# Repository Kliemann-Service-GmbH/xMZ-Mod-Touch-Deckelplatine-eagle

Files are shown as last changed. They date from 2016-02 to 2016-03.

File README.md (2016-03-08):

# xMZ-Mod-Touch
## Eagle Dateien Bodenplatine

## Howto's
### Material Listen (BOM) erstellen

Die Material Listen werden aus den Eagle Zeichnungen gewonnen. Hierzu werden in
Eagle zunächst über den "design link" alle Bauteile in der Farnell Datenbank
gesucht. Anschließend wird diese Liste gespeicherti (Design Link Export).

* Dateiname: "Deckelplatine $VERSION-order.txt"

Danach wird das bom.ulp in Eagle ausgeführt. Folgende Einstellungen sind zu
wählen:

	Listen-Typ: Werte (Häckchen unter "Attribute auflisten" setzen)
	Ausgabeformat: CSV

Diese Datei wird ebenfalls gespeichert.

* Dateiname: "Deckelplatine $VERSION BOM.csv"

### Farnell BOM Import

Farnell bietet die Möglichkeit über eine Web GUI die BOM Daten in eine
Bestellung umzuwandeln.

Format der CSV Datei für den Import:
- 3 Spalten ("Anzahl;	Ordercode; Beschreibung")
- Dateiformat .xlsx oder .xls

#Produktionsdaten
## Dokumentation Boardlayout Dateien

Einige der wichtigsten Ebenen (Drill, Solder, Paste) wurden einzeln zusammen
mit der "Document" Ebene (Layer 48) als PDF gedruckt (Siehe Script generate_documentaiont.scr).
Dieses PDF kann mit dem Ghostscript tool `gs` in ein PDF gewandelt werden.

```
cd doc

gs -dBATCH -dNOPAUSE -q -sDEVICE=pdfwrite -sOutputFile=Deckelplatine.pdf \
Deckelplatine-DIMENSIONS.pdf \
Deckelplatine-BOM.pdf \
Deckelplatine-Placement_TOP.pdf \
Deckelplatine-TOP.pdf \
Deckelplatine-BOTTOM.pdf \
Deckelplatine-BOTTOM-Solder-Mask.pdf \
Deckelplatine-TOP-Paste-Mask.pdf \
Deckelplatine-Drill-Drawing.pdf \
```

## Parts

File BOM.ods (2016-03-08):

Qty | Value | Device | Package | Parts | Description | DATASHEETURL | MF | MPN | OC_FARNELL | OC_FARNELL_ALTERNATIVE | OC_NEWARK | PARTNO
2 | 2AT | 01110005MR | 01110005MR | F1, F2 | Fuse Holder |  | LITTELFUSE | 01110005MR | 1155771 | 01110005MR
1 | 236-406/000-023 | 236-406/000-023 | P-236-406 | X1 | Stand: 01.01.2014. D | WAGO236_Connector Banana Pro Power SATA-WAGO236-402_WAGO236-403_WAGO236-404#WAG.pdf | WAGO | 236-406 | 1283529
2 | 2.7k | R-EU_R0603 | R0603 | R6, R7 | RESISTOR, European s |  | VISHAY | CRCW08052K70FKEA | 1469891
1 | LM2676S | LM2676S | TO-263-7 | U1 | LM2676 |  | TEXAS INSTRUMENTS | LM2676S-5.0/NOPB | 1564684
1 | CON 2x20 | PINHD-2X20 | 2X20 | JP1 | PIN HEADER |  | HARWIN | M20-6112045 | 1569232 | 1569230
1 | MAX1487EESA+ | MAX481CSA | SO08 | IC1 | RS485 TRANSEIVER |  | MAXIM INTEGRATED PRODUCTS | MAX1487EESA+. | 1593310 | 8452210 |  | MAX481CSA
3 | LL4005G | DIODE-MELF-MLL41 | MELF-MLL41 | D1, D3, D4 | DIODE |  | TAIWAN SEMICONDUCTOR | LL4005G | 1625106
5 | 10k | R-EU_R0603 | R0603 | R1, R2, R3, R4, R5 | RESISTOR, European s |  | TE CONNECTIVITY / NEOHM | CPF0603B10KE1 | 1697388
1 | 0.1uF | 08053C104KAT2A | 805 | C4 |  |  | AVX | 08053C104KAT2A | 1740665
1 | 52808-2570 | 52808-2570 | 52808-2570 | J1 | Molex 25pin header |  | MOLEX | 52808-2570 | 1757123
1 | 233-502 | 233-502 | P-233-502 | X2 | Serie 233, Klemmenl |  | WAGO | 233-502. | 1777096
1 | 0.01uF | GRM216R71H103KA01D | GRM216R71H103KA01D | C5 |  |  | MURATA | GRM216R71H103KA01D | 1828948
1 | 450mV | B340LB-13-F | SMB | D2 |  | http://www.diodes.com/datasheets/ds30240.pdf | DIODES INC. | B340LB-13-F | 1843684
5 | 74HCT595D | 74HCT595D | SO16 | IC2, IC3, IC4, IC5, IC6 | 8-bit SHIFT REGISTER |  | NXP | 74HCT595D | 2098004 |  |  | SMD HC 595
6 | 0.1uF | C-EUC0603 | C0603 | C3, C7, C8, C9, C10, C11 | CAPACITOR, European |  | KEMET | C0603C104K8RACTU | 2112833 |  |  | SMD TAN.0,1/35
1 | SRR1280-150M | SRR1280-150M | SRR1280 | L1 |  |  | COILCRAFT | MSS1278-153MLD | 2288501
1 | 120R | R-EU_R1206 | R1206 | R10 | RESISTOR, European s |  | TE CONNECTIVITY | CRGH1206F120R | 2332128
1 | 180.0 uF | 16SVP180MSM_RADIAL_10MM | SM_RADIAL_10MM | C6 |  |  | PANASONIC ELECTRONIC COMPONENTS | 16SVP180MX | 2354685 |  |  | RAD FC 560/35
2 | 4.7 uF | GRM21BR61E475MA12L | GRM21BR61E475MA12L | C1, C2 |  | http://www.murata.com/products/catalog/pdf/c02e.pdf | MURATA | GRM21BR61E475MA12L | 2362111
1 | CON 2x10 | PINHD-2X10 | 2X10 | JP3 | PIN HEADER |  | TE CONNECTIVITY / AMP | 5103308-5 | 2452432 | 9689621
2 | MM5Z3V3 | DIODE-SOD523 | SOD523 | D5, D6 | DIODE |  | FAIRCHILD SEMICONDUCTOR | MM5Z3V3 | 2454004
1 | '' | JP1E | JP1 | JP2 | JUMPER |  | TE CONNECTIVITY / AMP | 825433-2 | 3417645
2 | 1k | R-EU_R0603 | R0603 | R8, R9 | RESISTOR, European s |  | YAGEO (PHYCOMP) | RC0603FR-071KL. | 9238484
24 | 2.2k | R-EU_R0603 | R0603 | R11, R12, R13, R14, R15, R16, R17, R18, R19, R20, R21, R22, R23, R24, R25, R26, R27, R28, R29, R30, R31, R32, R33, R34 | RESISTOR, European s |  | YAGEO (PHYCOMP) | RC0603FR-072K2L. | 9238522 |  |  | SMD-0603 2,2K
4 | MOUNT-HOLE3.3 | MOUNT-HOLE3.3 | 3,3 | H1, H2, H3, H4 | MOUNTING HOLE with d |  |  |  | unknown

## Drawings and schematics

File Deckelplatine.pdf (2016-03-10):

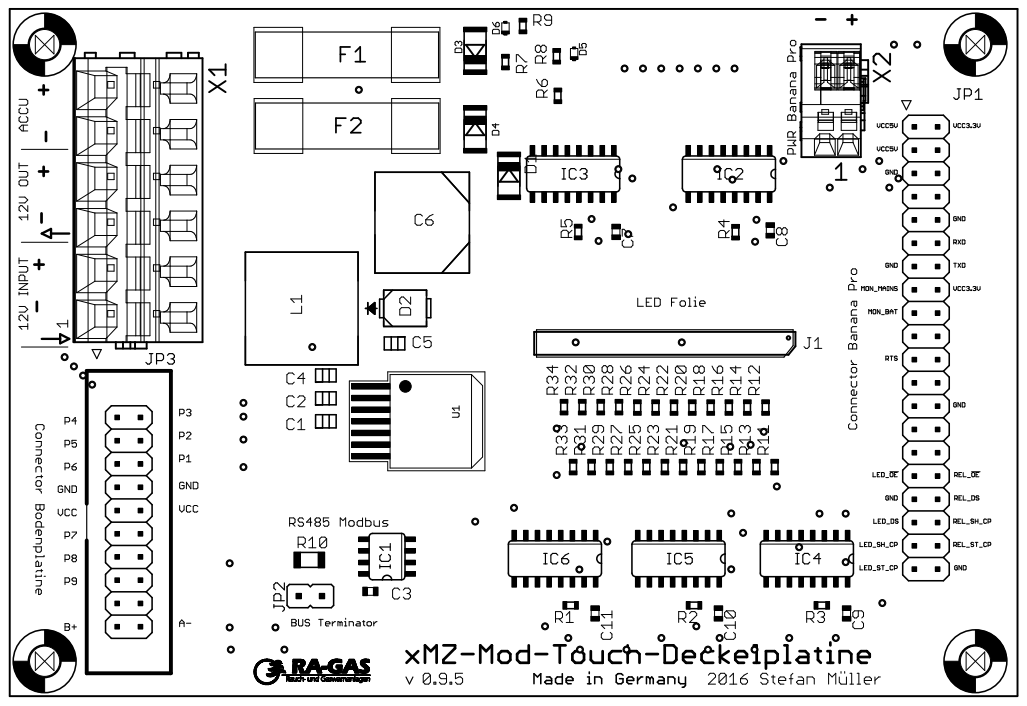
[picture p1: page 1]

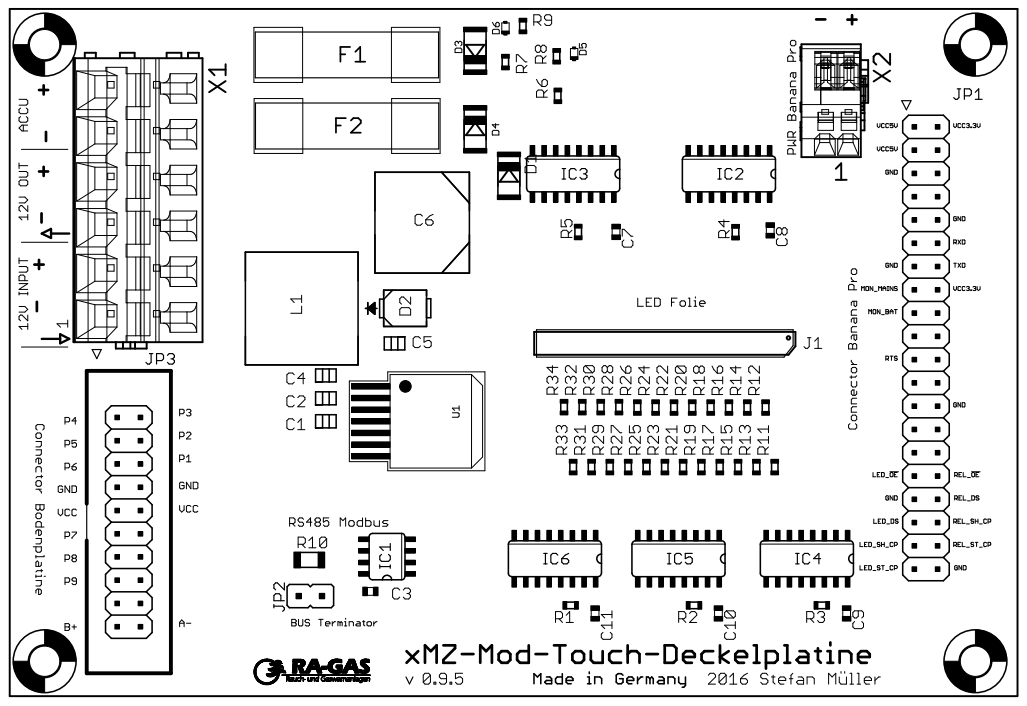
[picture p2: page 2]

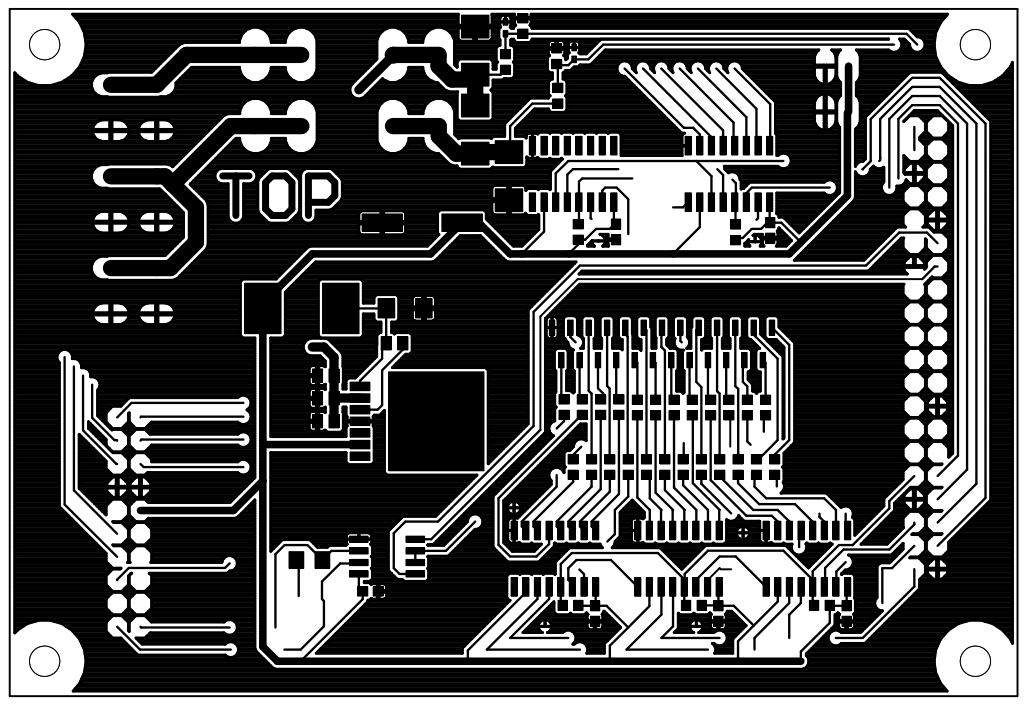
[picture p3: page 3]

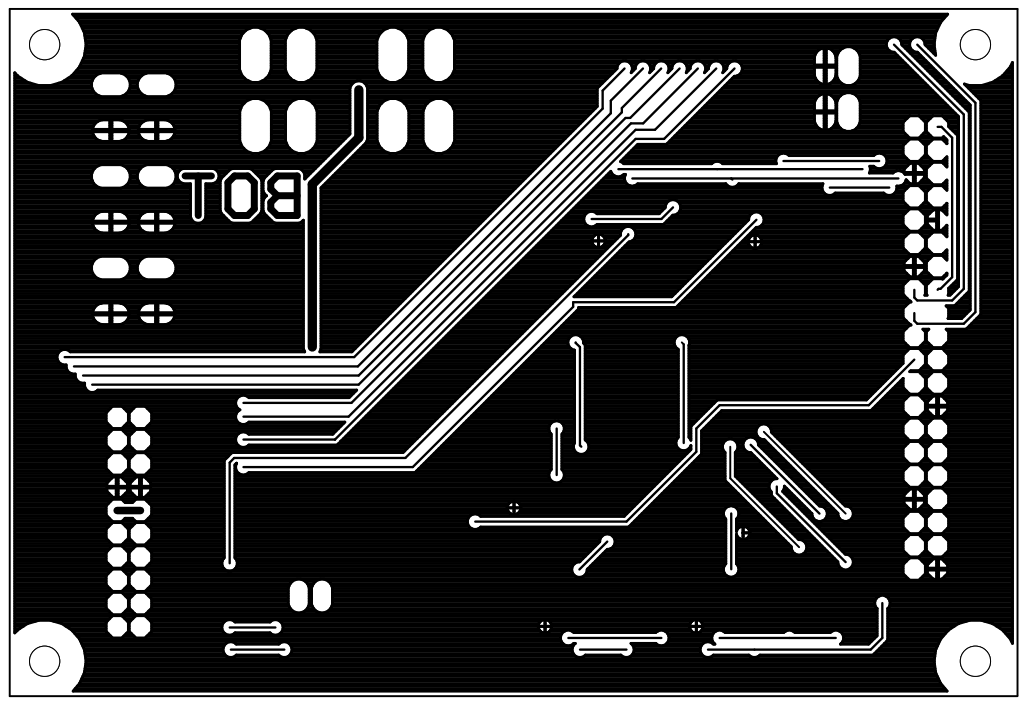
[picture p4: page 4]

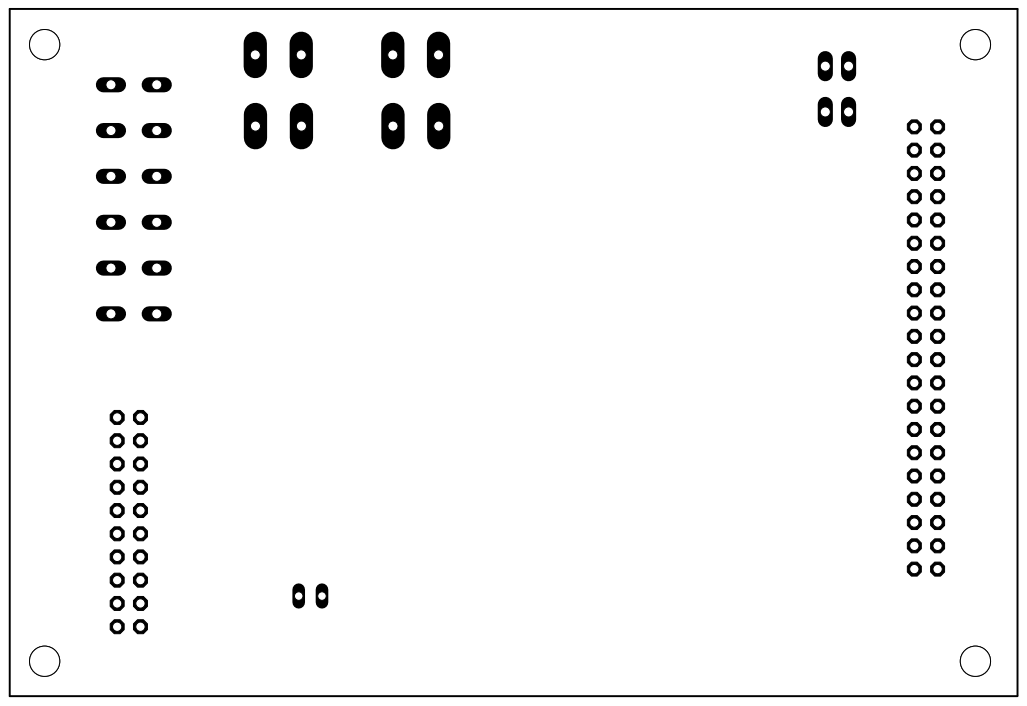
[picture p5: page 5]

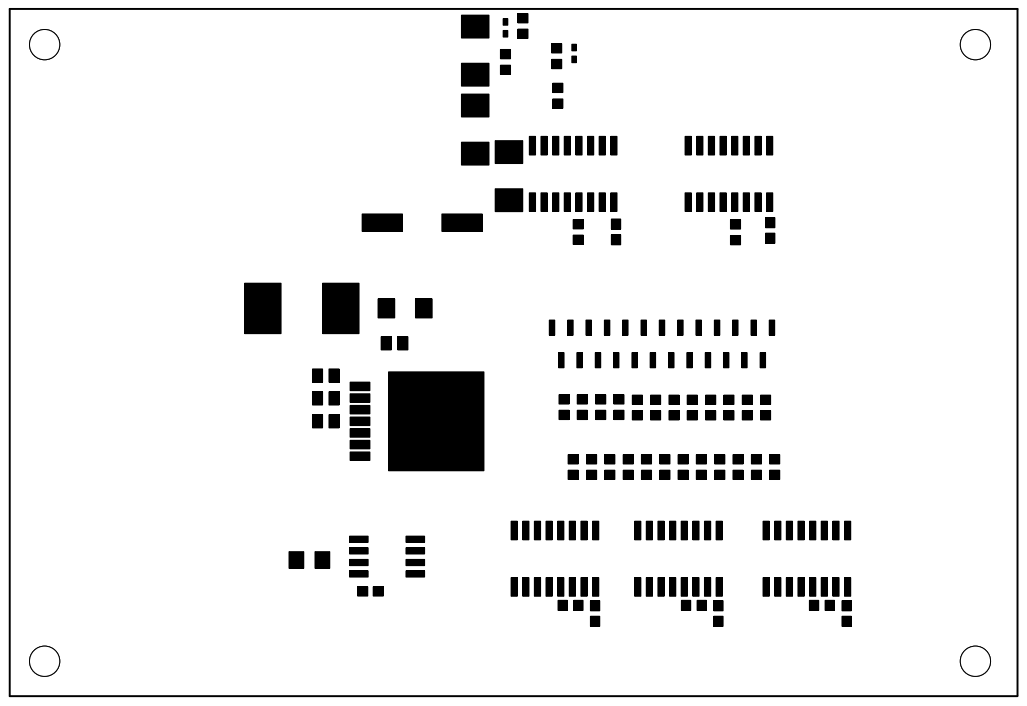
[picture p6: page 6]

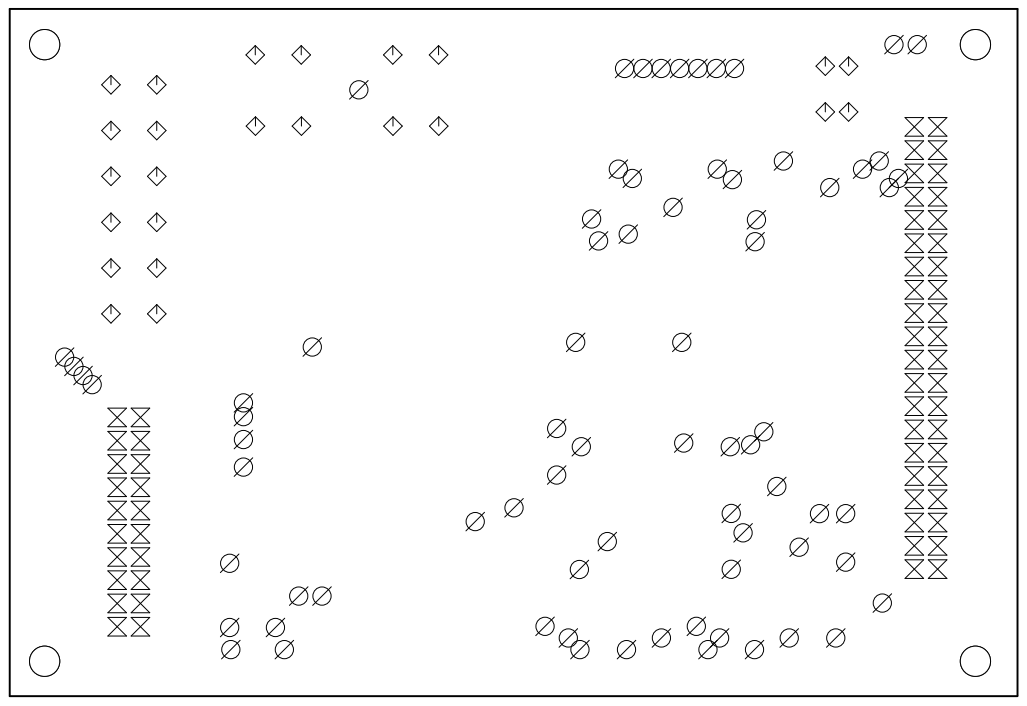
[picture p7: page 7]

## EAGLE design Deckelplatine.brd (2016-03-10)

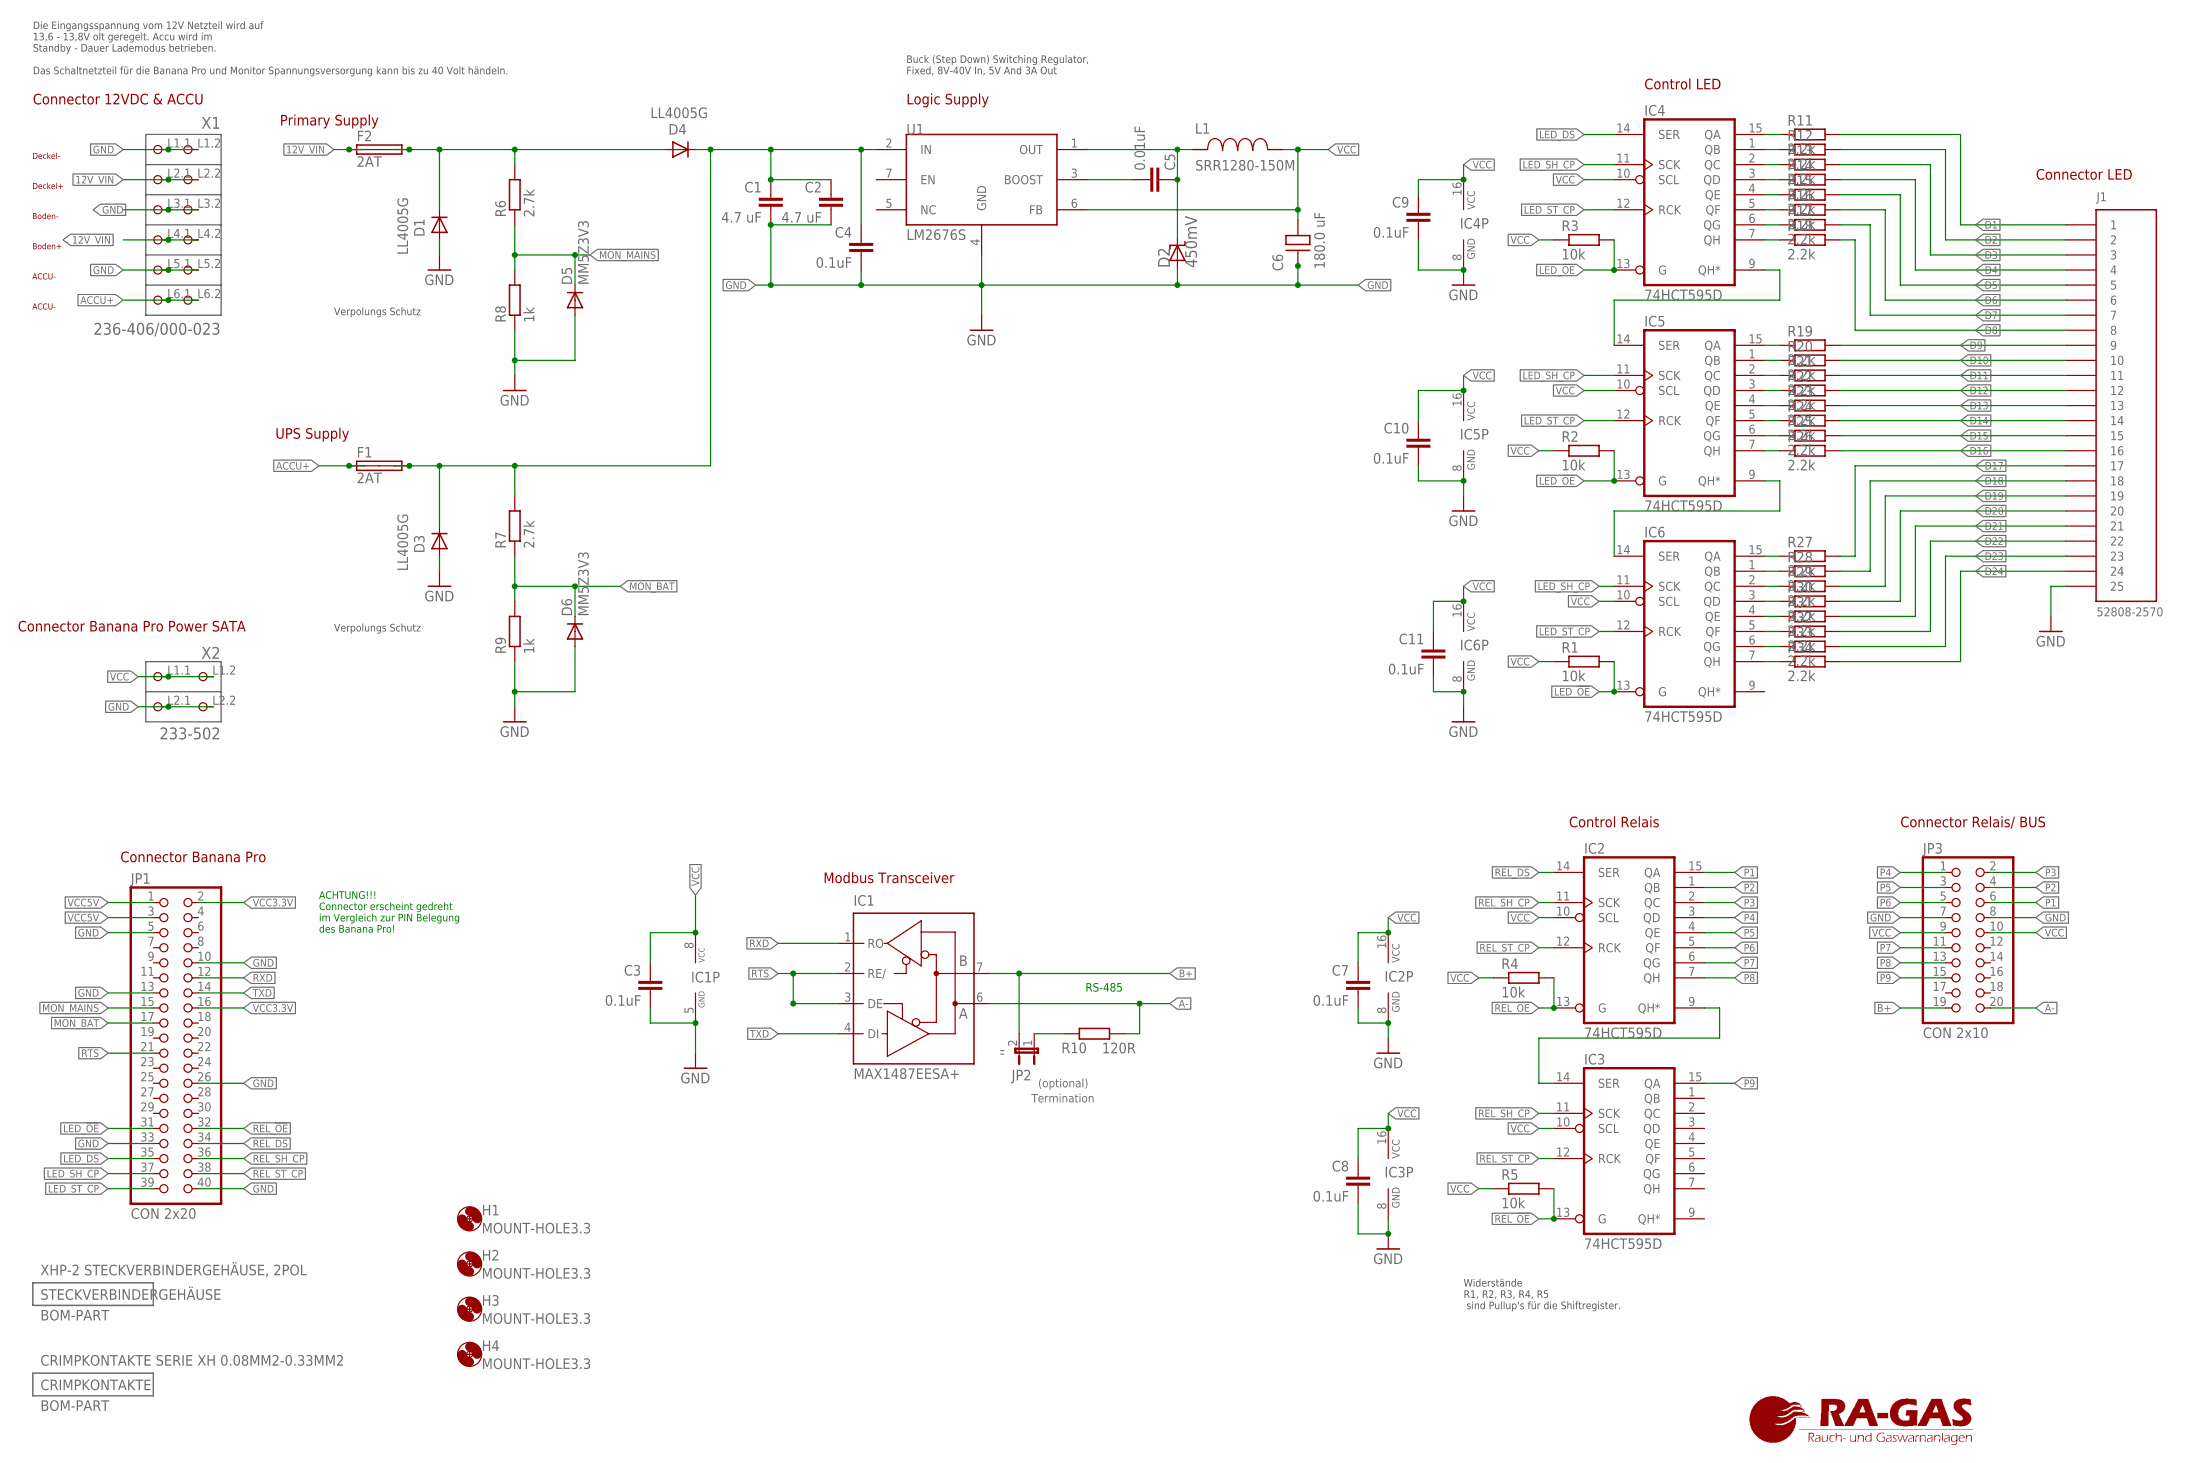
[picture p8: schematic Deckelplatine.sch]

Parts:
C1, C2: 4.7 uF; GRM21BR61E475MA12L; MPN GRM21BR61E475MA12L
C3, C7, C8, C9, C10, C11: 0.1uF; C0603; MPN C0603C104K8RACTU
C4: 0.1uF; 0805; MPN 08053C104KAT2A
C5: 0.01uF; GRM216R71H103KA01D; MPN GRM216R71H103KA01D
C6: 180.0 uF; SM_RADIAL_10MM; MPN 16SVP180MX
D1, D3, D4: LL4005G; MELF-MLL41; MPN LL4005G
D2: 450mV; SMB; MPN B340LB-13-F
D5, D6: MM5Z3V3; SOD523; MPN MM5Z3V3
F1, F2: 2AT; 01110005MR; MPN 01110005MR
H1, H2, H3, H4: MOUNT-HOLE3.3; 3,3
IC1: MAX1487EESA+; SO08; MPN MAX1487EESA+.
IC2, IC3, IC4, IC5, IC6: 74HCT595D; SO16; MPN 74HCT595D
J1: 52808-2570; MPN 52808-2570
JP1: CON 2x20; 2X20; MPN M20-6112045
JP2: ''; JP1; MPN 825433-2
JP3: CON 2x10; 2X10; MPN 5103308-5
L1: SRR1280-150M; SRR1280; MPN MSS1278-153MLD
R1, R2, R3, R4, R5: 10k; R0603; MPN CPF0603B10KE1
R6, R7: 2.7k; R0603; MPN CRCW08052K70FKEA
R8, R9: 1k; R0603; MPN RC0603FR-071KL.
R10: 120R; R1206; MPN CRGH1206F120R
R11, R12, R13, R14, R15, R16, R17, R18, R19, R20, R21, R22, R23, R24, R25, R26, R27, R28, R29, R30, R31, R32, R33, R34: 2.2k; R0603; MPN RC0603FR-072K2L.
U1: LM2676S; TO-263-7; MPN LM2676S-5.0/NOPB
X1: 236-406/000-023; P-236-406; MPN 236-406
X2: 233-502; P-233-502; MPN 233-502.

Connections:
12V_VIN: F2.1A, F2.1B, X1.L2.1 (P2.1), X1.L2.2 (P2.2), X1.L4.1 (P4.1), X1.L4.2 (P4.2)
A-: IC1.6 (A), JP3.20, R10.2
ACCU+: F1.1A, F1.1B, X1.L6.1 (P6.1), X1.L6.2 (P6.2)
B+: IC1.7 (B), JP2.2, JP3.19
D1: J1.1, R11.2
D2: J1.2, R12.2
D3: J1.3, R13.2
D4: J1.4, R14.2
D5: J1.5, R15.2
D6: J1.6, R16.2
D7: J1.7, R17.2
D8: J1.8, R18.2
D9: J1.9, R19.2
D10: J1.10, R20.2
D11: J1.11, R21.2
D12: J1.12, R22.2
D13: J1.13, R23.2
D14: J1.14, R24.2
D15: J1.15, R25.2
D16: J1.16, R26.2
D17: J1.17, R27.2
D18: J1.18, R28.2
D19: J1.19, R29.2
D20: J1.20, R30.2
D21: J1.21, R31.2
D22: J1.22, R32.2
D23: J1.23, R33.2
D24: J1.24, R34.2
GND: C1.2, C2.2, C3.2, C4.2, C6.2 (-), C7.2, C8.2, C9.2, C10.2, C11.2, D1.A, D2.A, D3.A, D5.A, D6.A, IC1.5 (GND), IC2.8 (GND), IC3.8 (GND), IC4.8 (GND), IC5.8 (GND), IC6.8 (GND), J1.25, JP1.5, JP1.10, JP1.13, JP1.26, JP1.33, JP1.40, JP3.7, JP3.8, R8.1, R9.1, U1.4 (GND), X1.L1.1 (P1.1), X1.L1.2 (P1.2), X1.L3.1 (P3.1), X1.L3.2 (P3.2), X1.L5.1 (P5.1), X1.L5.2 (P5.2), X2.L2.1 (P2.1), X2.L2.2 (P2.2)
LED_!OE: IC4.13 (G), IC5.13 (G), IC6.13 (G), JP1.31, R1.2, R2.2, R3.2
LED_DS: IC4.14 (SER), JP1.35
LED_SH_CP: IC4.11 (SCK), IC5.11 (SCK), IC6.11 (SCK), JP1.37
LED_ST_CP: IC4.12 (RCK), IC5.12 (RCK), IC6.12 (RCK), JP1.39
MON_BAT: D6.C, JP1.17, R7.1, R9.2
MON_MAINS: D5.C, JP1.15, R6.1, R8.2
unnamed: IC5.9 (QH*), IC6.14 (SER)
unnamed: IC2.9 (QH*), IC3.14 (SER)
unnamed: C1.1, C2.1, C4.1, D3.C, D4.C, F1.2A, F1.2B, R7.2, U1.2 (IN)
unnamed: IC4.9 (QH*), IC5.14 (SER)
unnamed: IC4.15 (QA), R11.1
unnamed: IC4.1 (QB), R12.1
unnamed: IC4.2 (QC), R13.1
unnamed: IC4.3 (QD), R14.1
unnamed: IC4.4 (QE), R15.1
unnamed: IC4.5 (QF), R16.1
unnamed: IC4.6 (QG), R17.1
unnamed: IC4.7 (QH), R18.1
unnamed: IC5.15 (QA), R19.1
unnamed: IC5.1 (QB), R20.1
unnamed: IC5.2 (QC), R21.1
unnamed: IC5.3 (QD), R22.1
unnamed: JP2.1, R10.1
unnamed: IC5.4 (QE), R23.1
unnamed: IC5.5 (QF), R24.1
unnamed: IC5.6 (QG), R25.1
unnamed: IC5.7 (QH), R26.1
unnamed: IC6.15 (QA), R27.1
unnamed: IC6.1 (QB), R28.1
unnamed: IC6.2 (QC), R29.1
unnamed: IC6.3 (QD), R30.1
unnamed: IC6.4 (QE), R31.1
unnamed: IC6.5 (QF), R32.1
unnamed: IC6.6 (QG), R33.1
unnamed: IC6.7 (QH), R34.1
unnamed: D1.C, D4.A, F2.2A, F2.2B, R6.2
unnamed: C5.2, U1.3 (BOOST)
unnamed: C5.1, D2.C, L1.1, U1.1 (OUT)
P1: IC2.15 (QA), JP3.6
P2: IC2.1 (QB), JP3.4
P3: IC2.2 (QC), JP3.2
P4: IC2.3 (QD), JP3.1
P5: IC2.4 (QE), JP3.3
P6: IC2.5 (QF), JP3.5
P7: IC2.6 (QG), JP3.11
P8: IC2.7 (QH), JP3.13
P9: IC3.15 (QA), JP3.15
REL_!OE: IC2.13 (G), IC3.13 (G), JP1.32, R4.2, R5.2
REL_DS: IC2.14 (SER), JP1.34
REL_SH_CP: IC2.11 (SCK), IC3.11 (SCK), JP1.36
REL_ST_CP: IC2.12 (RCK), IC3.12 (RCK), JP1.38
RTS: IC1.2 (RE/), IC1.3 (DE), JP1.21
RXD: IC1.1 (RO), JP1.12
TXD: IC1.4 (DI), JP1.14
VCC: C3.1, C6.1 (+), C7.1, C8.1, C9.1, C10.1, C11.1, IC1.8 (VCC), IC2.10 (SCL), IC2.16 (VCC), IC3.10 (SCL), IC3.16 (VCC), IC4.10 (SCL), IC4.16 (VCC), IC5.10 (SCL), IC5.16 (VCC), IC6.10 (SCL), IC6.16 (VCC), JP3.9, JP3.10, L1.2, R1.1, R2.1, R3.1, R4.1, R5.1, U1.6 (FB), X2.L1.1 (P1.1), X2.L1.2 (P1.2)
VCC3.3V: JP1.2, JP1.16
VCC5V: JP1.1, JP1.3

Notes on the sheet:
Connector Relais/ BUS
Connector Banana Pro
RS-485
Termination
(optional)
Modbus Transceiver
Connector LED
Control LED
Control Relais
Connector 12VDC & ACCU
UPS Supply
Primary Supply
Logic Supply
Connector Banana Pro Power SATA
ACCU-
ACHTUNG!!! Connector erscheint gedreht im Vergleich zur PIN Belegung des Banana Pro!
Boden-
Boden+
Deckel-
Deckel+
Widerstände R1, R2, R3, R4, R5 sind Pullup's für die Shiftregister.
Verpolungs Schutz
Buck (Step Down) Switching Regulator, Fixed, 8V-40V In, 5V And 3A Out
Die Eingangsspannung vom 12V Netzteil wird auf 13,6 - 13,8V olt geregelt. Accu wird im Standby - Dauer Lademodus betrieben. Das Schaltnetzteil für die Banana Pro und Monitor Spannungsversorgung kann bis zu 40 Volt händeln.

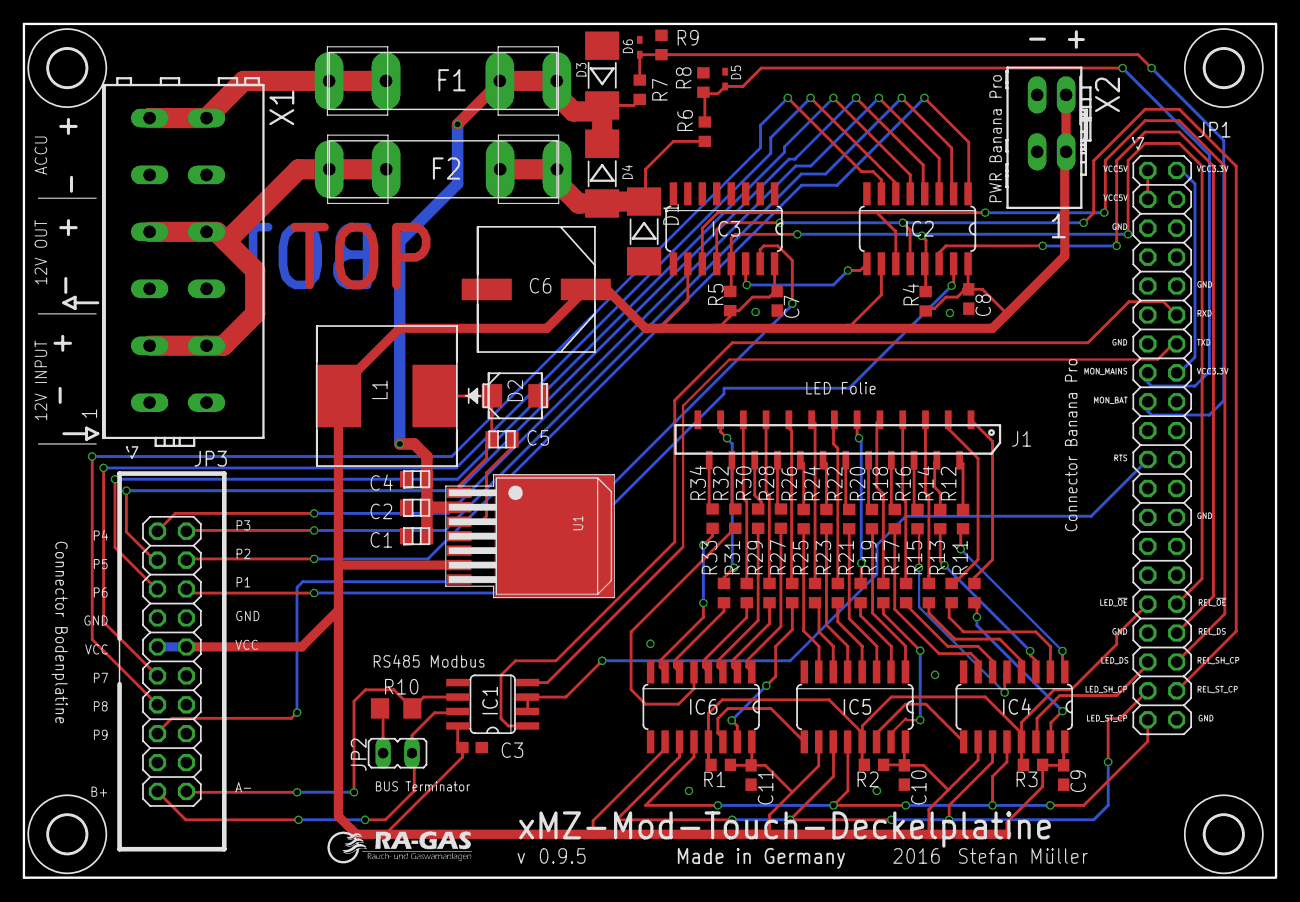
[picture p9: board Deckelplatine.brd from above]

Board: 2 copper layers, 110.0 x 75.0 mm, 74 parts (0 on the bottom side), 86 nets.

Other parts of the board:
U$3: TEXT_NAME_VERSION_AUTHOR-SMALL
U$5: A3-LOC-RA-GAS
U$6: LOGO_RA-GAS-SMALL

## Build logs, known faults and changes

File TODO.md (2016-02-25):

* Relais shift registers mit pull down/ pull up ausschalten bis der Banana Pro sie manuell aktiviert.

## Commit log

2016-02-25 Erste .gitignore Version
    Diese Version ignoriert die Eagle Sicherheitskopien.
2016-02-25 Import Deckelplatine Dateien aus dem master Branch
    Der Master Branch des alten Repos (Deckelplatine und Bodenplatine
    zusammen)
    [Deckelplatine.brd, Deckelplatine.sch]
2016-02-25 Shift Register Pullup Widerstände eingefügt
    [Deckelplatine.brd, Deckelplatine.sch]
2016-02-26 Realis Shift Register verschoben
    Die Schiebe Register für die Relais waren dem Stecker für die Verbindung zur Bodenplatine im Weg.
    [Deckelplatine.brd, Deckelplatine.sch]
2016-03-08 BAT und MAINS Monitor
    Konnectoren in eigener Bibliothek 'Deckelplatine.lbr'
    [Deckelplatine.brd, Deckelplatine.sch]
2016-03-08 Keine Airwire und DRC ist OK
    Sparkfun Design-Rule Check ist noch nicht erfüllt, hauptsächlich Winkel der Leiterbahnen und Abstände zu gering.
    [Deckelplatine.brd, Deckelplatine.sch]
2016-03-08 PIN1 Nummern
    Kleiner gemacht und etwas verschoben so dass sie nicht mehr mit der Board Bezeichnung der Eingänge kollidieren.
2016-03-08 BOM und kontrolliert und eingfügt
    [BOM.ods, Deckelplatine.brd, Deckelplatine.sch]
2016-03-10 Board auf Koordinaten 0x0 ausgerichtet
    [Deckelplatine.brd]
2016-03-10 Sichtbaren TOP und BOTTOM Layer eingefuegt
    [Deckelplatine.brd]
2016-03-10 Fehler BOTTOM Layer Markierung gefixt
    [Deckelplatine.brd]

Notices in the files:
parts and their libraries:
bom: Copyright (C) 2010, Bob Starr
